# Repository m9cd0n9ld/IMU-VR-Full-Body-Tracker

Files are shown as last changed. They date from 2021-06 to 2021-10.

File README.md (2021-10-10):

# IMU-VR-Full-Body-Tracker
 Inside-out full body tracker for Steam VR based on ESP32 with BNO080/085 IMU.  
 Support up to 2 BNO08X IMUs per ESP32 via I2C communication.  
 No base station is required, completely wireless using WiFi UDP.  
 Should be compatible with any VR headset that supports Steam VR.  
 <p align="middle">
 
 
 </p>
 
## Hardware Example
 **LILYGO® TTGO T7 V1.5 Mini32 ESP32-WROVER-B** with **GY-BNO08X**  
 <p align="middle">
 
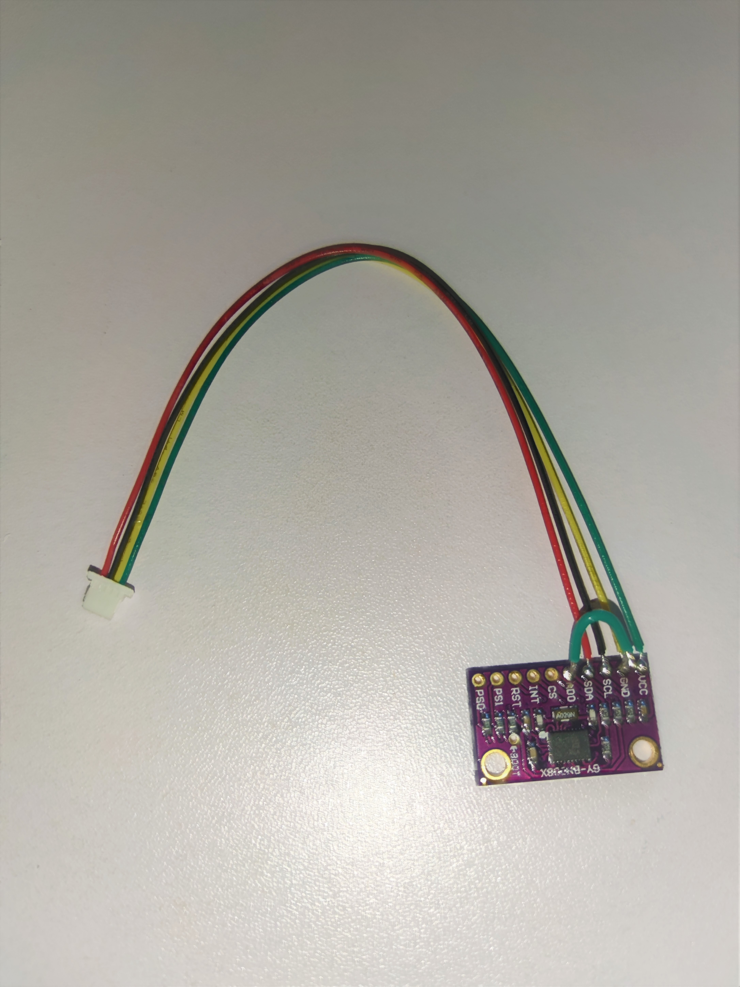
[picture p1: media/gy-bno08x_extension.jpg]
 
 <p/>
 <p align="middle">
 
 
 
 <p/>
 <p/>
 <p align="middle">
 
 <p/>

## Instruction
 1. Extract steamvr.driver.zip and copy imuFBT folder to (Steam directory)\steamapps\common\SteamVR\drivers.  
 2. Extract esp32.sketch.zip, edit the settings (pin settings, etc.) in esp32_settings.h file.  
 3. Upload the sketch to ESP32 microcontroller with Arduino IDE (SparkFun_BNO080_Arduino_Library Arduino library is required).  
 4. Extract desktop.server.zip. Add imufbtserver.exe and backend/imuFBTServerBackend.exe to Windows firewall exception list to allow UDP to work properly.  
 5. Run the imufbtserver.exe (might trigger antivirus false positive, known problem for unsigned PyInstaller exe files).  
 6. Set the tracker sensor frame to driver frame (X right, Y up, Z back) XYZ intrinsic rotation based on the mounting orientation, body segment length, tracker virtual position and offset settings when standing in T-pose** in **Main settings** and **Tracker virtual position settings** tab.  
 7. Activate required tracker devices to be output to SteamVR. In some SteamVR game/program, the hand controllers might lose tracking or not working if too many tracker devices are activated.  
 8. Set the tracker floor level offset (tracker min Y value to prevent clipping) if necessary.  
 9. Enable lower leg tracker data as SteamVR feet tracker if want to use lower leg tracker as foot role. Feet tracker device must still be activated.  
 10. Save the settings by pressing **Save settings** button or load an existing saved settings by pressing **Load settings** button in **Main settings** tab. The last saved/loaded settings will be automatically loaded in the next instance.  
 <p align="middle">
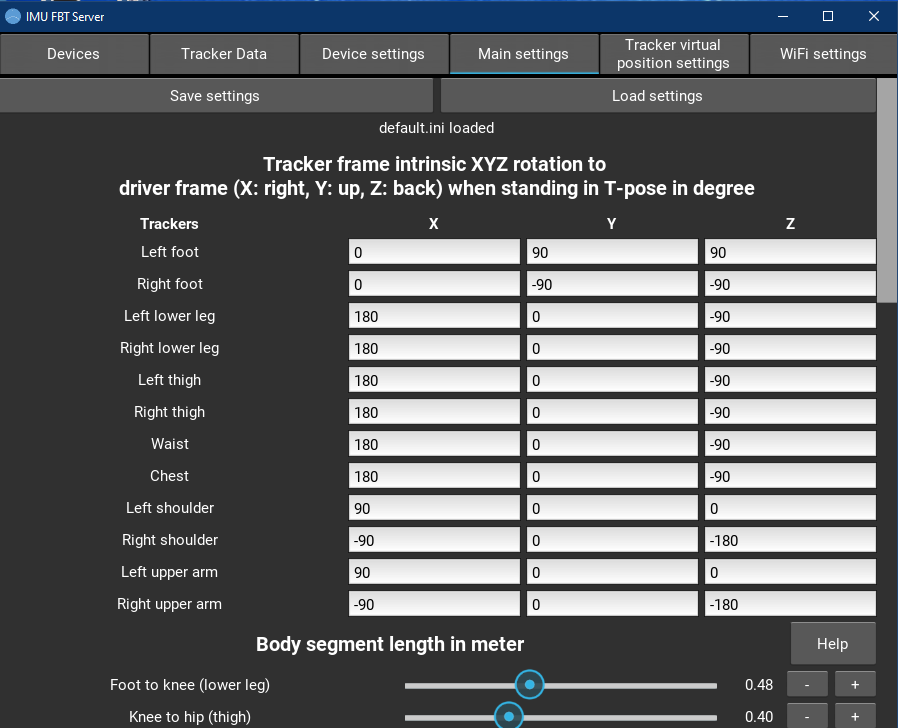
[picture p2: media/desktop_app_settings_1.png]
 
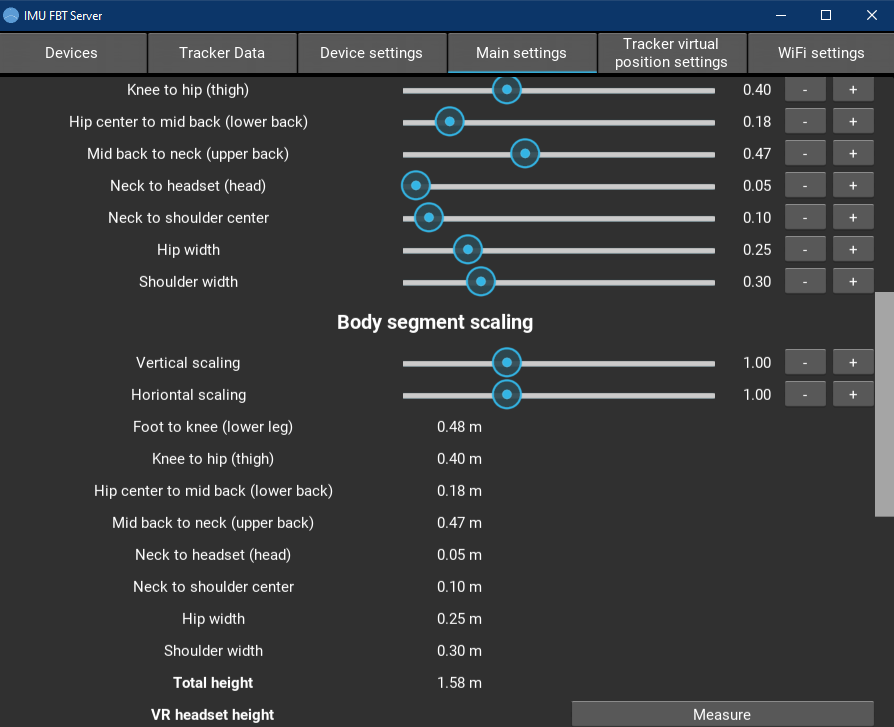
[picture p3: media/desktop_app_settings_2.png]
 
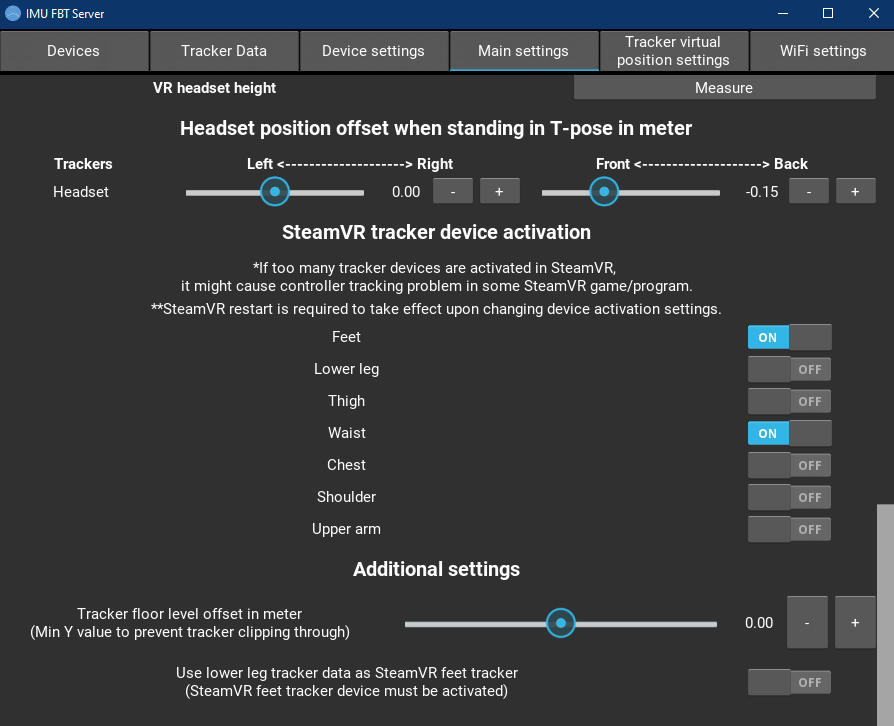
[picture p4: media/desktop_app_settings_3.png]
 
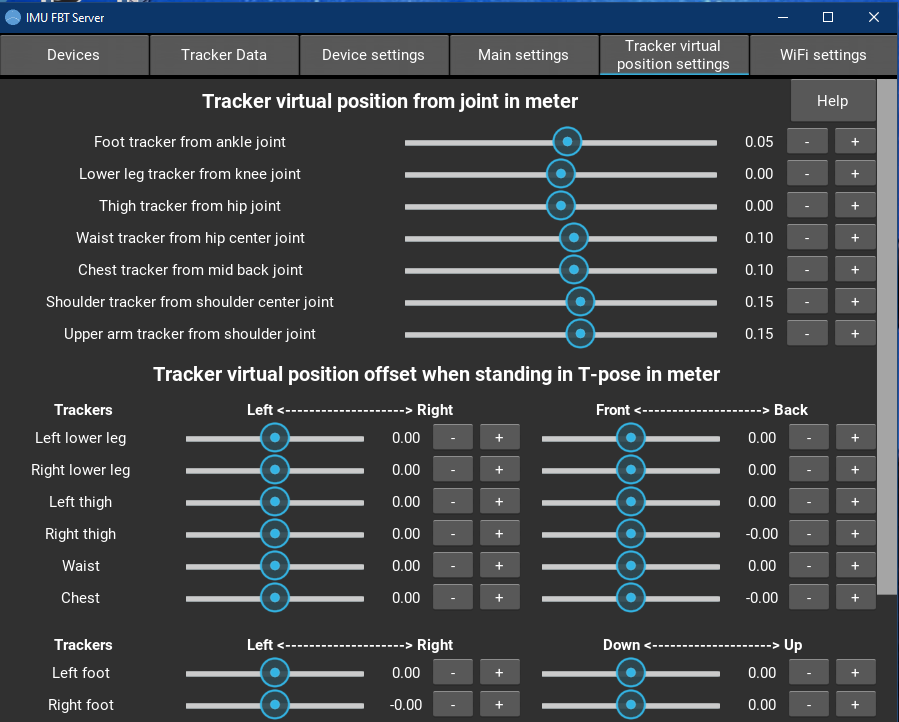
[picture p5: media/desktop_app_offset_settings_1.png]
 
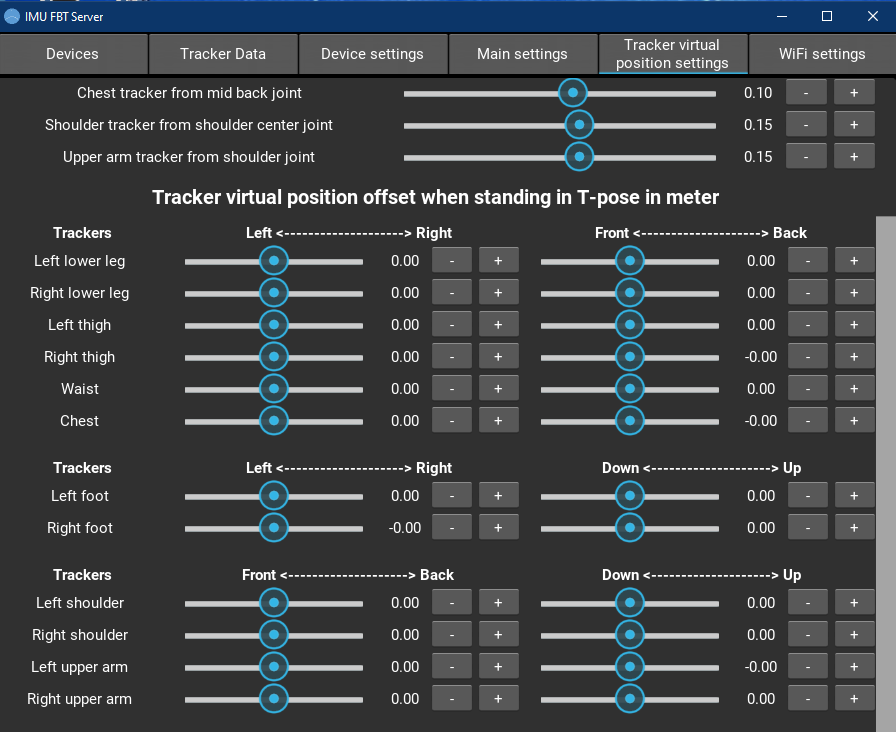
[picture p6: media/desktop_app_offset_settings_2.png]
 
 <p/>
 
 11. Plug in USB cable to ESP32 and set the WiFi credential in **WiFi Settings** tab.  
 <p align="middle">
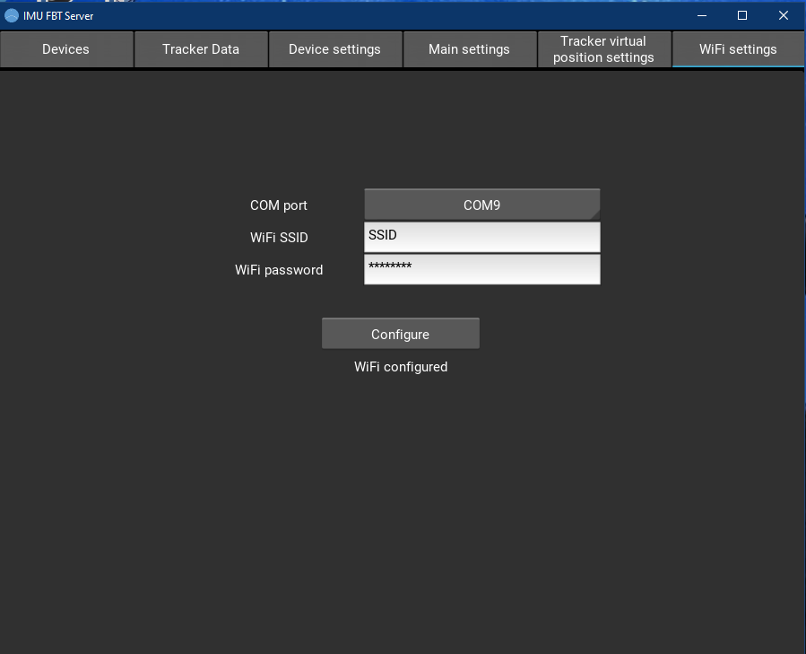
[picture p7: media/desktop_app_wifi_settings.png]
 
 <p/>
 
 12. Once WiFi credential is configured, unplug the USB cable and power cycle the ESP32 to establish WiFi connection.  
 13. The trackers will be listed in **Device settings** tabs.  
 14. Set the IMU mode, WiFi TX power, WiFi power saving mode and role of the trackers in **Device settings** tab.  
 <p align="middle">
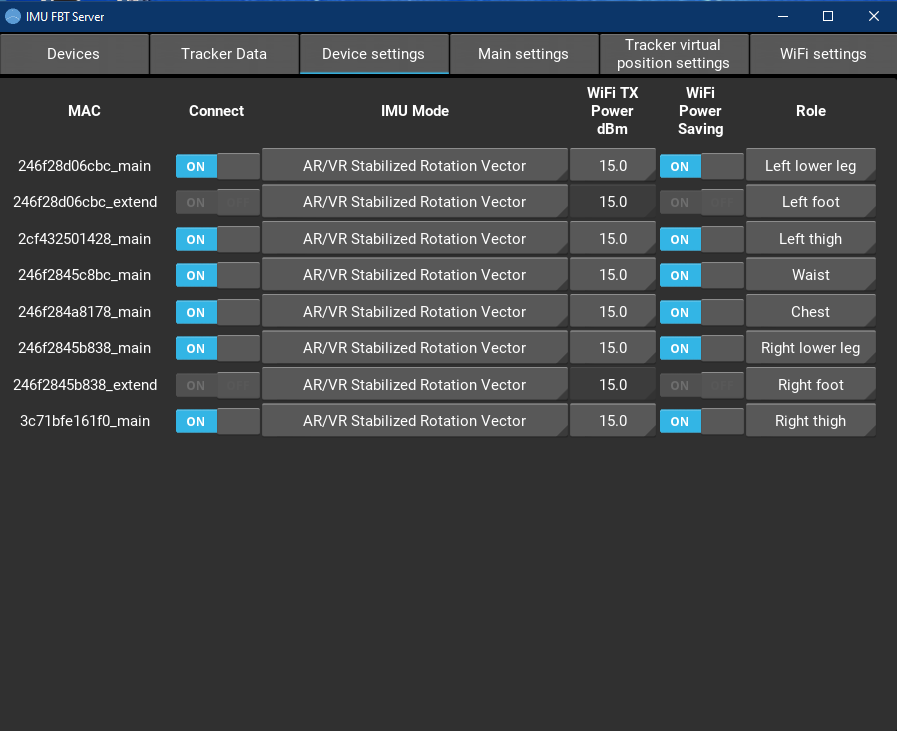
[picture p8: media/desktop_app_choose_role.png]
 
 <p/>
 
 15. Click **Connect** slider, and the trackers with correct settings will be shown in **Devices** tab.  
 16. Save the settings in **Main settings** tab to save the device settings.  
 <p align="middle">
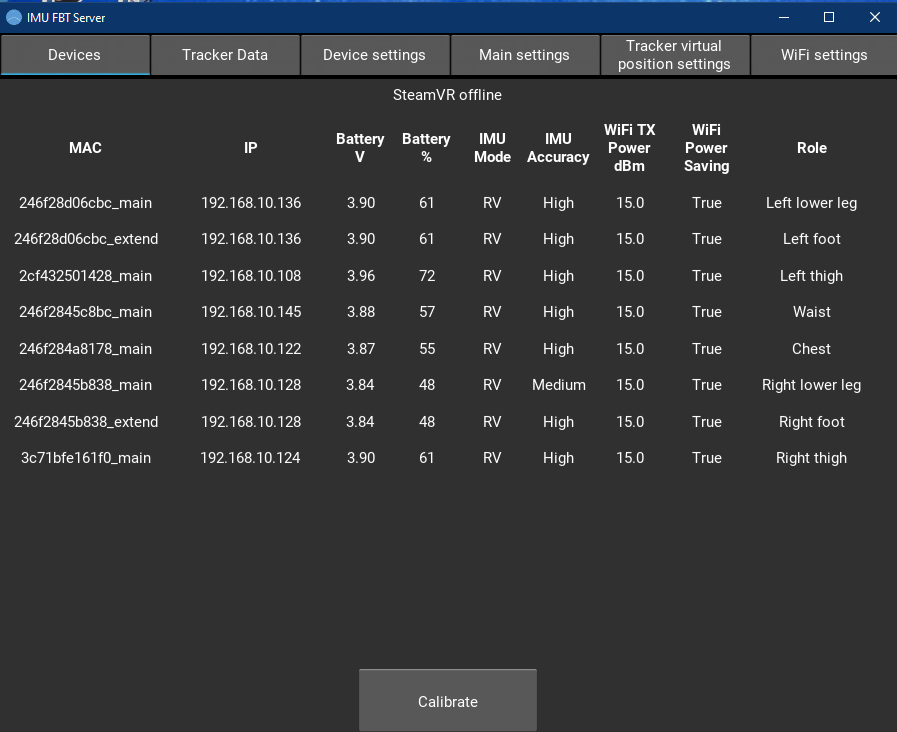
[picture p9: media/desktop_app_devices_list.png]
 
 <p/>
 
 17. Mount the trackers according to the following diagram. For feet/leg tracking, chest tracker, waist tracker, thigh trackers and lower leg trackers are required. Feet trackers are optional. For elbow tracking, chest tracker, shoulder trackers and upper arm trackers are required.  
 <p align="middle">
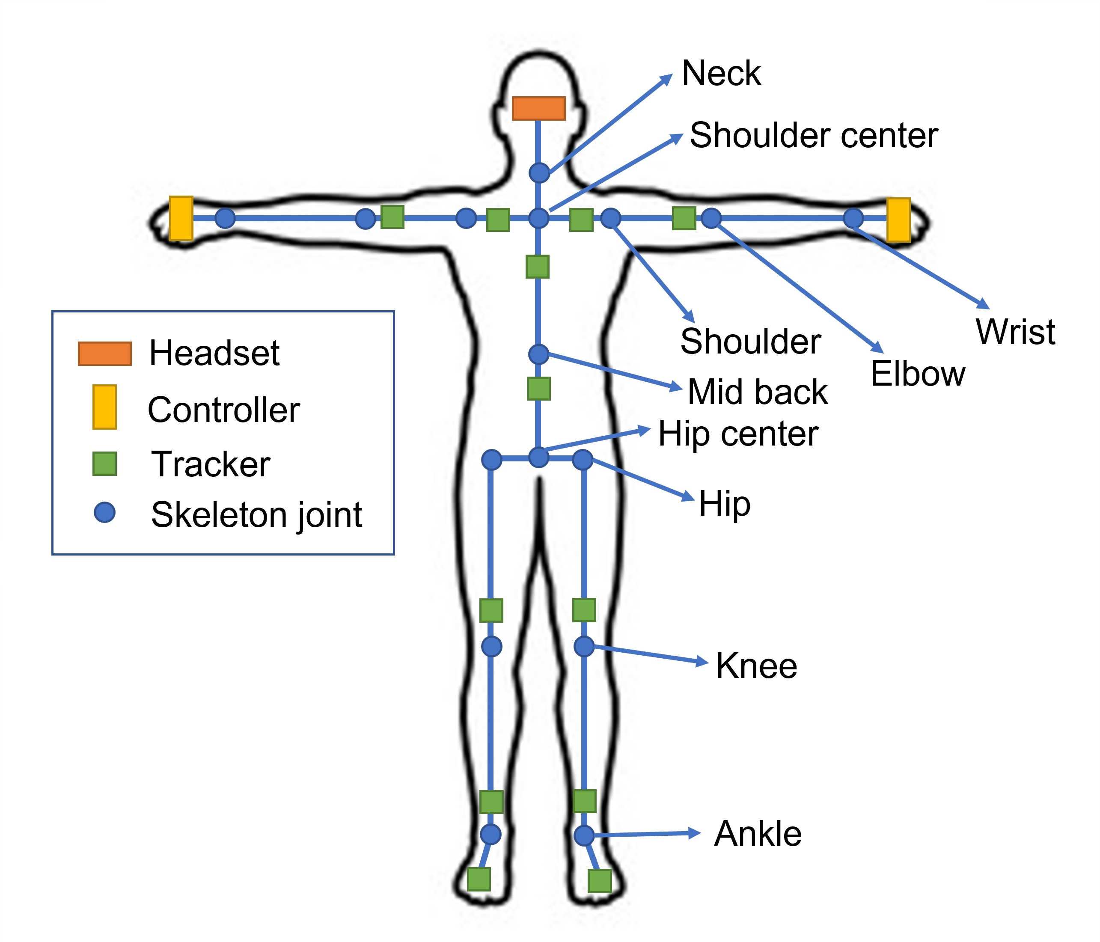
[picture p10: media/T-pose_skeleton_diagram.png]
 
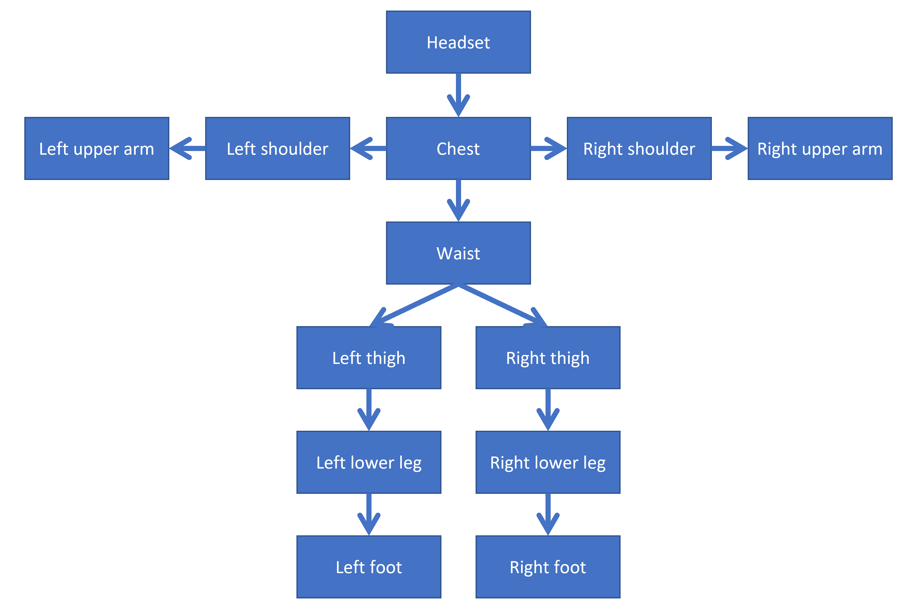
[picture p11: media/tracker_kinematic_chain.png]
 
 <p/>
 
 18. Open SteamVR. The top of the **Devices** tab will show SteamVR online when SteamVR is detected.  
 19. The trackers will be shown in SteamVR environment at weird position and orientation on startup.  
 20. Stand in T-pose**, then press **Calibrate** button in **Devices** tab to realign/calibrate the trackers.  
 <p align="middle">
 
 <p/>
 
 21. Tracker output data can be seen on **Tracker Data** tab.  
 <p align="middle">
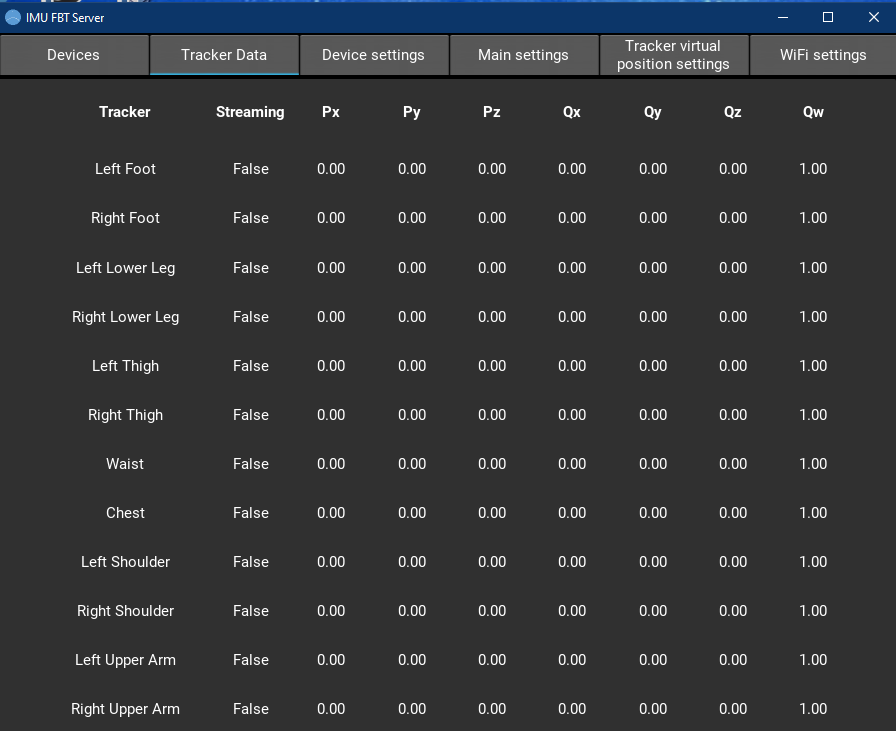
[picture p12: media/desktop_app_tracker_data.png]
 
 <p/>
 
 22. Done!  
 <p align="middle">
 
 
 <p/>
 
 **Stand straight look forward with feet pointing forward and hip-width apart in T-pose with palm facing down.

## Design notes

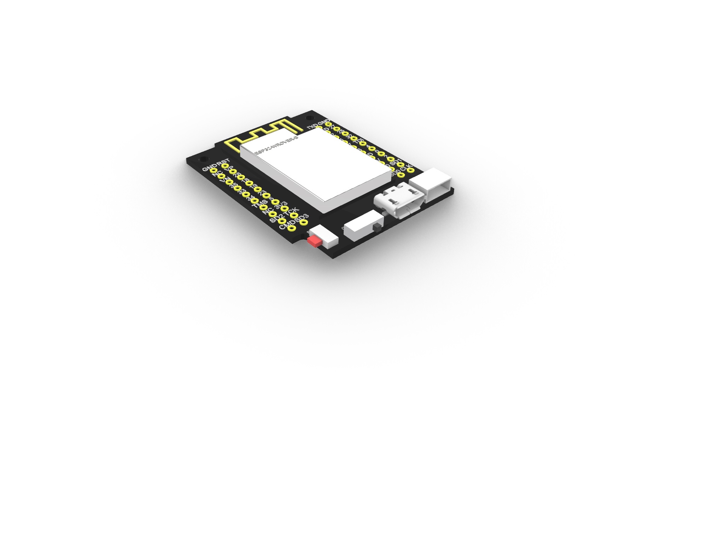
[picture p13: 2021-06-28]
hardware example/TTGO-T7-V1.5_GY-BNO08X_enclosure/esp32-lilygo-t7-mini-v1-4-1.snapshot.2/ttgo_mini_b.jpg

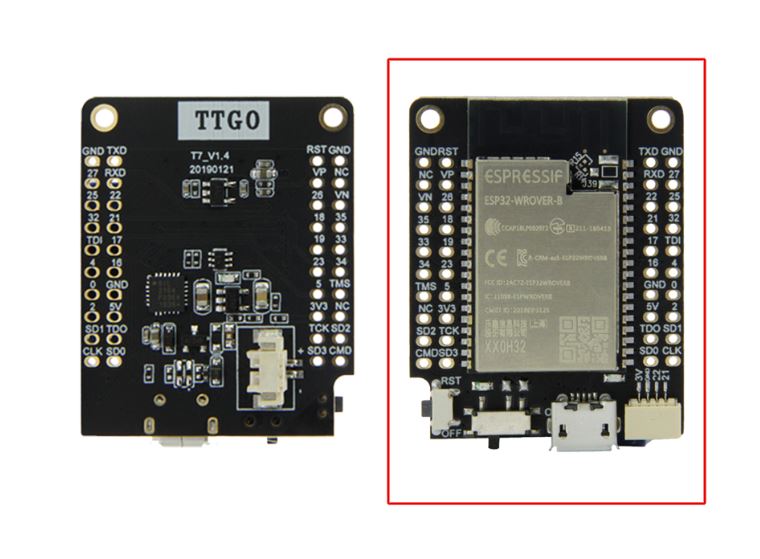
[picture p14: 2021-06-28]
hardware example/TTGO-T7-V1.5_GY-BNO08X_enclosure/esp32-lilygo-t7-mini-v1-4-1.snapshot.2/ESP32 LILYGO T7 TTGO MINI.JPG

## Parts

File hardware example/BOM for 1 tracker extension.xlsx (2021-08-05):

Items | Quantity
GY-BNO08X | 1
JST-SH 1mm pitch 4 pin cable | 1
10mm M2 female-female standoff | 2
12mm M2 female-female standoff | 2
5mm M2 screw | 6
8mm M2 screw | 2
GY-BNO08X extension enclosure | 1
30 mm width strap | 1

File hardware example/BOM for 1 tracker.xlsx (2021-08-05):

Items | Quantity
TTGO T7 v1.5 | 1
GY-BNO08X | 1
TTGO T7 v1.5 - GY-BNO08X breakout board | 1
803040 LiPo | 1
0.1" 1x10 female header with 5mm height | 2
0.1" 1x10 male header for 5mm female header | 2
13mm M2 female-female standoff | 2
27mm M3 female-female standoff | 4
5mm M2 screw | 4
5mm M3 screw | 8
TTGO T7 v1.5 - GY-BNO08X enclosure | 1
38 mm width strap | 1

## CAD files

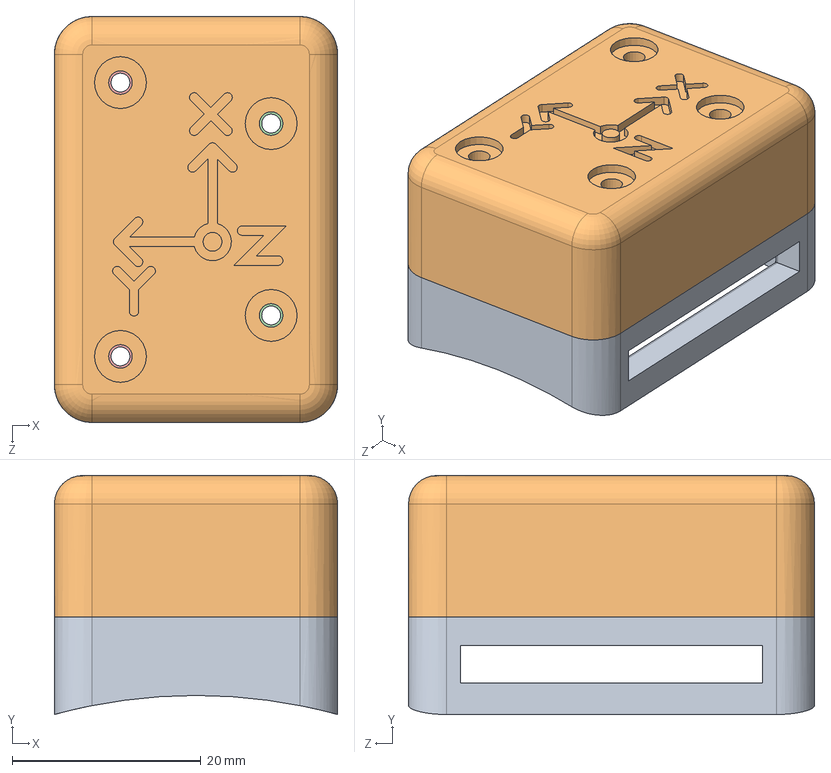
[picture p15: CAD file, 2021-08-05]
hardware example/GY-BNO08X_extension_enclosure/assembly.SLDASM
30.0 x 25.3 x 43.0 mm
base
cover
GY-BNO08X
m2x10-standoff x 2
m2x12-standoff x 2

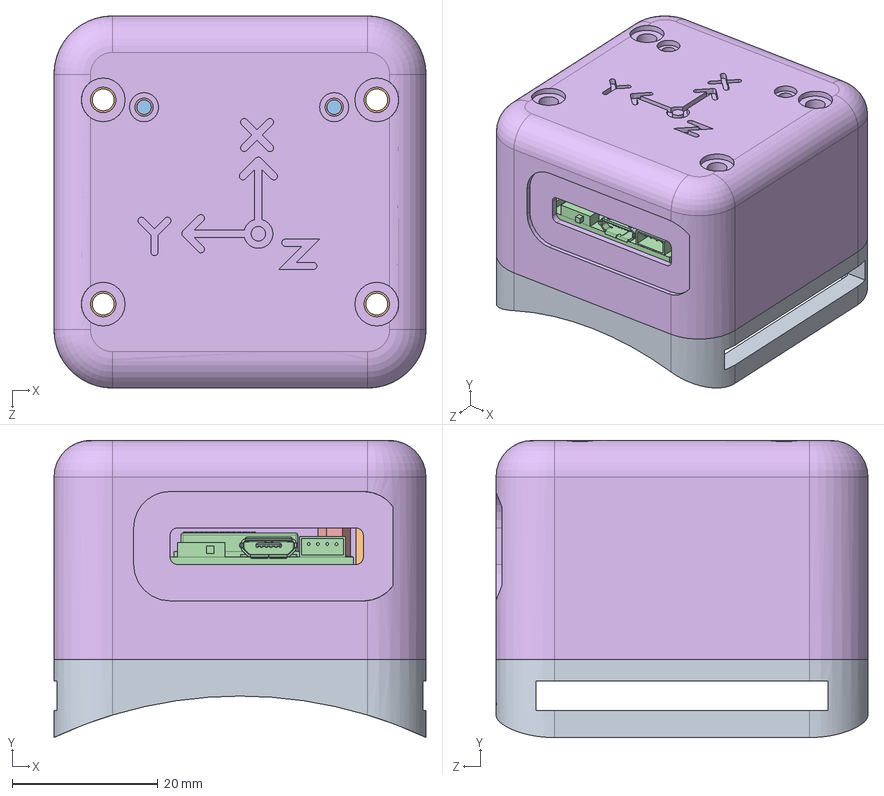
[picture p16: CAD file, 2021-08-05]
hardware example/TTGO-T7-V1.5_GY-BNO08X_enclosure/assembly.SLDASM
51.0 x 40.7 x 51.0 mm
base
m3-standoff x 4
LiPo-803040
ttgo_t7_v1.5_board
m2-standoff x 2
cover

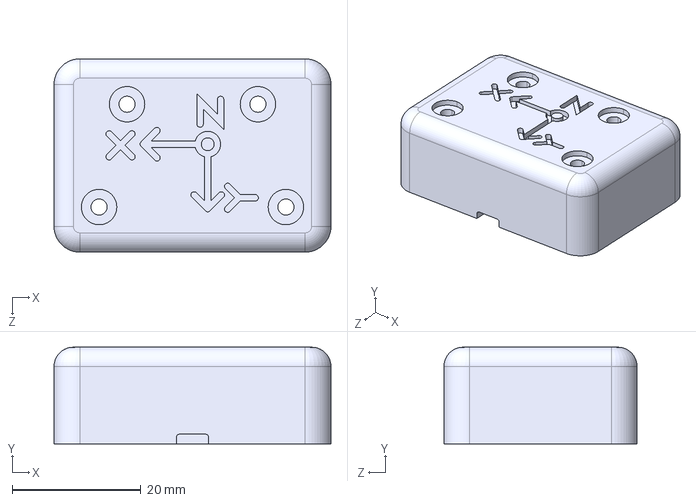
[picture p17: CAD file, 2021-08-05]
hardware example/GY-BNO08X_extension_enclosure/stp/cover.STEP
43.0 x 15.0 x 30.0 mm

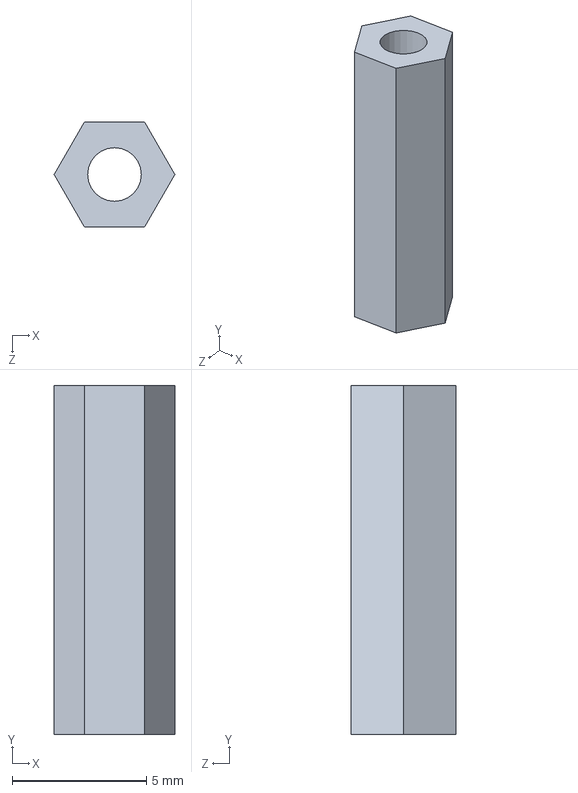
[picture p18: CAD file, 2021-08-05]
hardware example/TTGO-T7-V1.5_GY-BNO08X_enclosure/m2-standoff.SLDPRT
4.50 x 13.0 x 3.90 mm

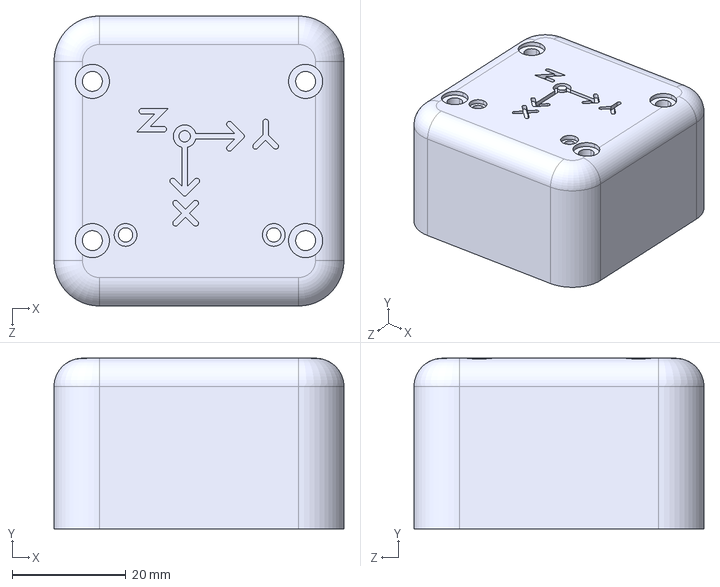
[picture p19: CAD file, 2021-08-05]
hardware example/TTGO-T7-V1.5_GY-BNO08X_enclosure/stp/cover.STEP
51.0 x 30.0 x 51.0 mm

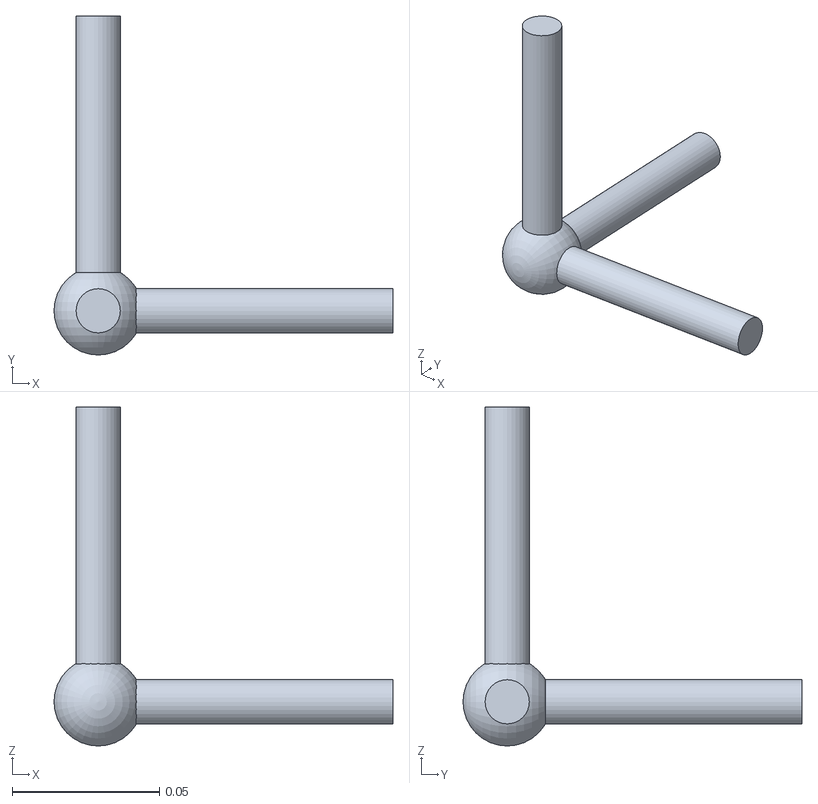
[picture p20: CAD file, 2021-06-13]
steamvr_openvr_driver/driver_imuFBT/resources/resources/rendermodels/frame/frame.obj
0.115 x 0.115 x 0.115

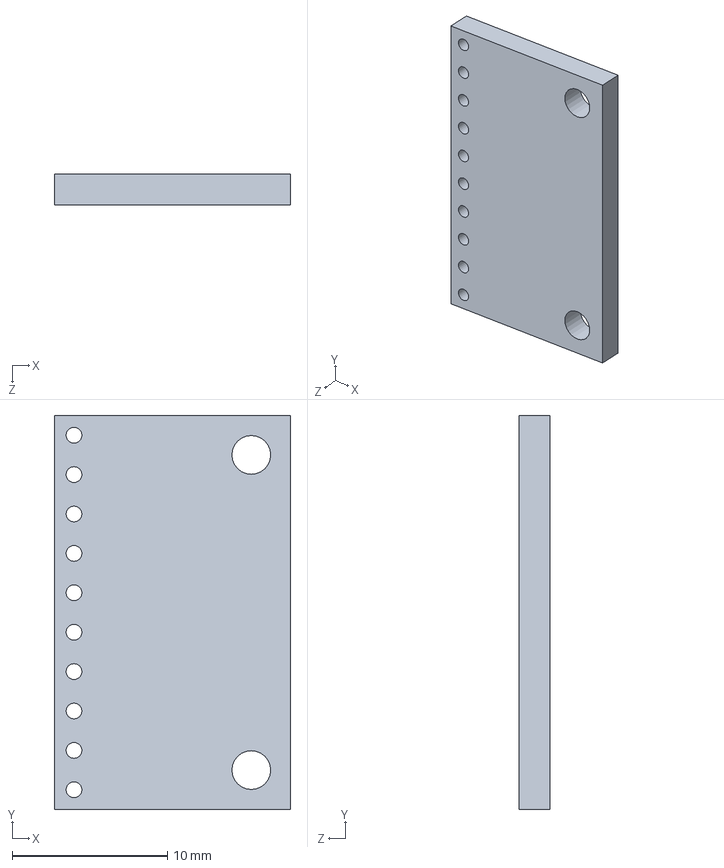
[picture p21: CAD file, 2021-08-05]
hardware example/GY-BNO08X_extension_enclosure/GY-BNO08X.SLDPRT
15.2 x 25.4 x 2.00 mm

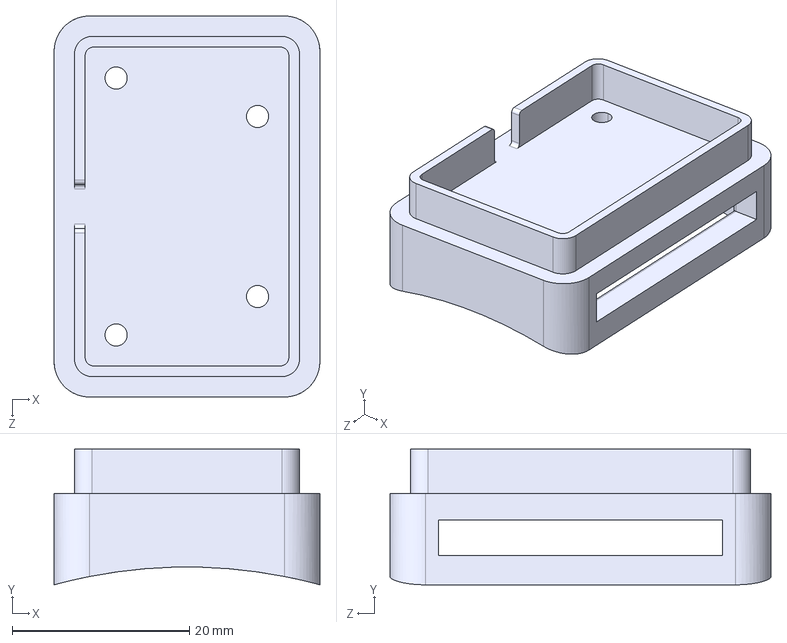
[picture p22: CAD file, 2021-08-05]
hardware example/GY-BNO08X_extension_enclosure/stp/base.STEP
30.0 x 15.3 x 43.0 mm

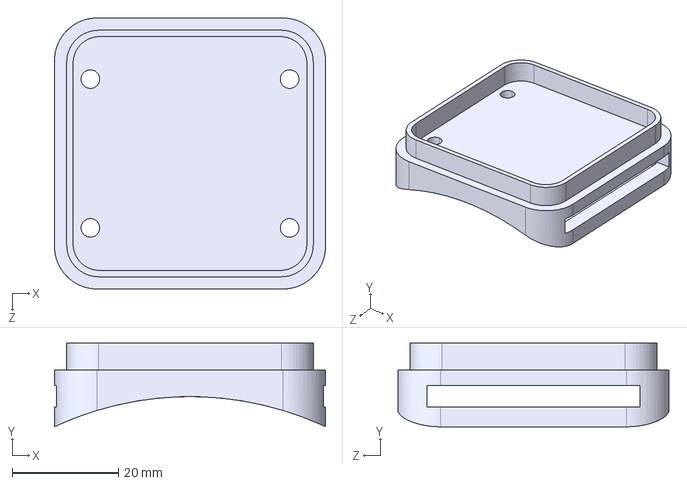
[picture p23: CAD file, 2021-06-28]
hardware example/TTGO-T7-V1.5_GY-BNO08X_enclosure/stp/base.STEP
51.0 x 15.7 x 51.0 mm

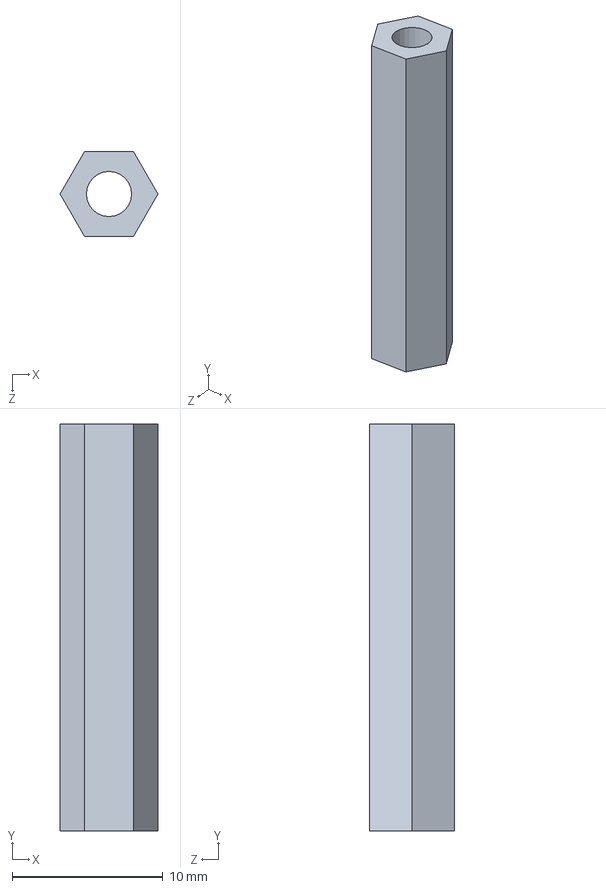
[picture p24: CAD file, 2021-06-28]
hardware example/TTGO-T7-V1.5_GY-BNO08X_enclosure/m3-standoff.SLDPRT
6.50 x 27.0 x 5.63 mm

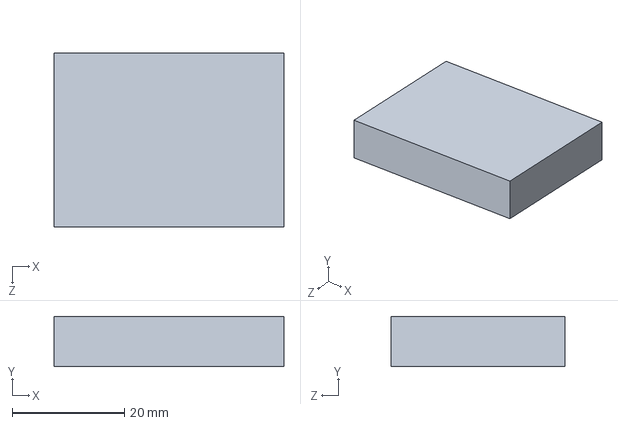
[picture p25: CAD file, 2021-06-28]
hardware example/TTGO-T7-V1.5_GY-BNO08X_enclosure/LiPo-803040.SLDPRT
41.0 x 9.00 x 31.0 mm

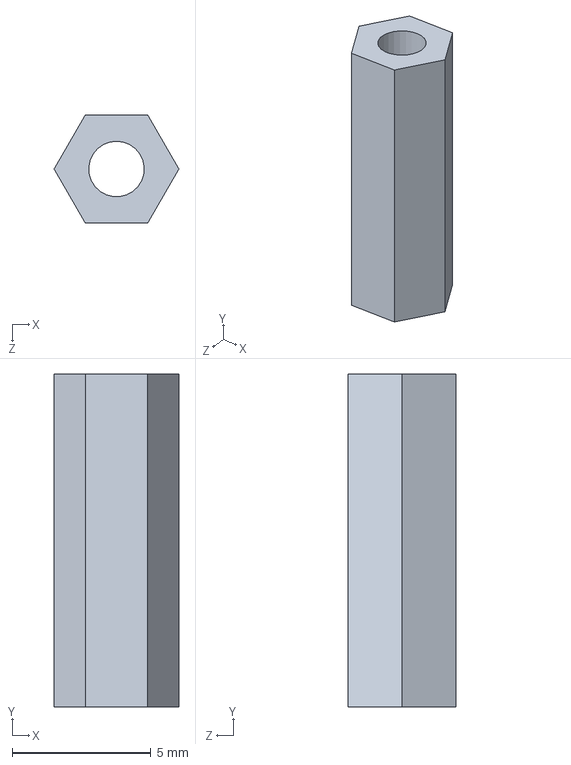
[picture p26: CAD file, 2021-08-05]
hardware example/GY-BNO08X_extension_enclosure/m2x12-standoff.SLDPRT
4.50 x 12.0 x 3.90 mm

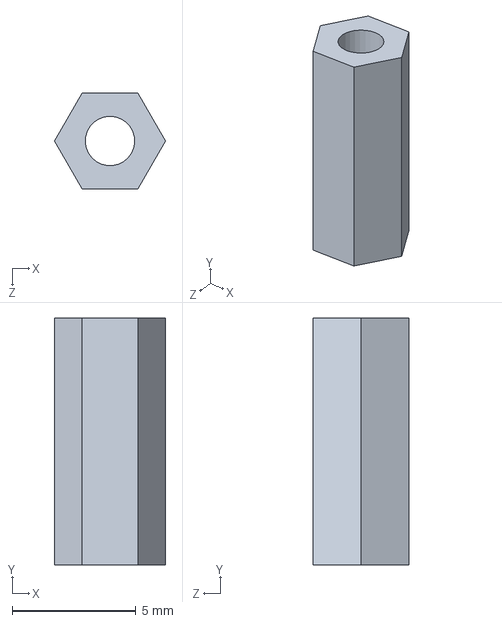
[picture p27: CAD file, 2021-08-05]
hardware example/GY-BNO08X_extension_enclosure/m2x10-standoff.SLDPRT
4.50 x 10.0 x 3.90 mm

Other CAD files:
hardware example/GY-BNO08X_extension_enclosure/base.SLDPRT
hardware example/GY-BNO08X_extension_enclosure/cover.SLDPRT
hardware example/TTGO-T7-V1.5_GY-BNO08X_enclosure/base.SLDPRT
hardware example/TTGO-T7-V1.5_GY-BNO08X_enclosure/cover.SLDPRT

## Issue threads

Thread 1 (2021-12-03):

BNO055

kennibaz, 2021-12-03:
Is it possible to substitute BNO085 with BNO055?

m9cd0n9ld, 2021-12-04:
As long as the IMU sensor or AHRS algorithm can provide quaternion in ENU coordinate, any IMU sensor can be used, just need to do some minor modification in the Arduino sketch code. But for best result, it's better to use high quality AHRS output IMU such as BNO085, etc.

kennibaz, 2021-12-04:
Thanks for your reply. The reason I’m asking about the substitute is bc
there is a huge shortage of bno085.
Could be mpu 6050 used as well?

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

m9cd0n9ld, 2021-12-04:
I see mpu6050 can output quaternion, shouldn't be a problem.

kennibaz, 2021-12-04:
Great, thanks!

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

Closed 2021-12-04.

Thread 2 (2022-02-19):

Pose estimates from 6 IMUs

NoLoPhe, 2022-02-19:
Hi!

I made pose estimates from 6 IMUs based on the results of the paper TransPose.
I want it to work with VRchat. How do I do that?

I don't see documentation to send skeleton coordinates to Openvr.

Thankyou!

Link: https://twitter.com/Tn23008624/status/1494618444821839877

m9cd0n9ld, 2022-02-19:
Dear @NoLoPhe , you need to create Steam VR driver that reads the skeleton coordinates data, then output them as steam tracker devices to Steam VR. You can refer to steamvr_openvr_driver directory for example.

NoLoPhe, 2022-02-19:
@m9cd0n9ld Thanks for the quick response, I'll take a look at the code.

Closed 2022-02-22.

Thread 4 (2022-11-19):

Need help in understanding the code's logic

TparT, 2022-11-19:
Hi there! Im looking into making a full body tracking suit for a school project and I found your repo which looks really nice.
Only problem is I cant figure out much about the order of the logic, like how and when do I set the tracker location, when is the data transmitted to SteamVR etc..

We could also move to a different chatting platform like Discord if that would make things easier.

So, if you could help me out and guide me through the code it would be very very appreciated :D

m9cd0n9ld, 2022-11-21:
Hi @TparT,

If you are interested in algorithm behind it, you can just implement this [header](https://github.com/m9cd0n9ld/IMU-VR-Full-Body-Tracker/blob/main/imuFBTServerBackend/headers/kinematics.h) file to your project. It might not be the best solution for full body tracking.

TparT, 2022-11-23:
Okay, I guess I missed the part where you need to enable the trackers in the 'Main settings' tab really down there. Thanks anyways for replying and trying to help :D

Closed 2022-11-23.

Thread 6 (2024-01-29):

Looking for some help

erik-aranda, 2024-01-29:
Hi, I try to make a **MPU6050 remplacement** to the device that using right now but I don't have it cuz in my country it costs 80 usd each one, and MPU6050 it costs 7 usd. So **if you have some code that help me will be nice.** Also I am testing with python but I don't see that the bones move correctly. I mean that it will only hand moves but the others bones never. So I was looking for the error and for now I check driver IMU folder and **some files are without information some are with "None" parameters** and this is wrong. **I need make sure that right now your original code it works, please confirm me too if is working in this date with your original sensor.**

[erik-aranda:patch-1](url)

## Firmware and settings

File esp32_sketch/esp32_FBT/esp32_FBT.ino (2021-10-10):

#include <esp_wifi.h>
#include <WiFi.h>
#include <WiFiUdp.h>
#include <AsyncUDP.h>
#include "esp32_settings.h"
#include <Wire.h>
#include "SparkFun_BNO080_Arduino_Library.h"

#define DEBUG false
#define DEBUG_PRINT if(DEBUG)Serial

#define ROTVEC 0
#define GAMEROTVEC 1

char header[128];
char networkSSID[128];
char networkPassword[128];
uint16_t serialLength;

IPAddress udpAddress(0, 0, 0, 0);
const uint16_t broadPort = 6969;
uint16_t serverPort = 0;
uint16_t driverPort = 0;

bool connected = false;

WiFiUDP udp;
AsyncUDP Audp;

struct __attribute__((packed)) PingBroad {
  uint8_t header = (uint8_t)'I';
  uint8_t id = 77;
  uint8_t a;
  uint8_t b;
  uint8_t c;
  uint8_t d;
  uint8_t e;
  uint8_t f;
  bool extend = false;
  uint8_t footer = (uint8_t)'i';
} pingbroad;

struct __attribute__((packed)) Ping {
  uint8_t header = (uint8_t)'I';
  uint8_t id = 0;
  uint8_t id_ext = 0;
  uint8_t a;
  uint8_t b;
  uint8_t c;
  uint8_t d;
  uint8_t e;
  uint8_t f;
  float batt = 0;
  uint8_t mode;
  uint8_t mode_ext;
  uint8_t accuracy = 0;
  uint8_t accuracy_ext = 0;
  uint8_t wifi_power;
  uint8_t wifi_sleep;
  bool extend = false;
  uint8_t footer = (uint8_t)'i';
} ping;

struct __attribute__((packed)) Ack {
  uint8_t header;
  uint8_t reply;
  uint8_t id;
  uint8_t id_ext;
  uint8_t mode;
  uint8_t mode_ext;
  uint8_t wifi_power;
  uint8_t wifi_sleep;
  uint16_t serverPort;
  uint16_t driverPort;
  uint8_t footer;
} ack;

struct __attribute__((packed)) PayloadExt {
  uint8_t header = (uint8_t)'I';
  uint8_t id = 0;
  int16_t x = 0;
  int16_t y = 0;
  int16_t z = 0;
  int16_t w = 32767;
  uint8_t id_ext = 0;
  int16_t x_ext = 0;
  int16_t y_ext = 0;
  int16_t z_ext = 0;
  int16_t w_ext = 32767;
  uint8_t footer = (uint8_t)'i';
} payloadext;

struct __attribute__((packed)) Payload {
  uint8_t header = (uint8_t)'I';
  uint8_t id = 0;
  int16_t x = 0;
  int16_t y = 0;
  int16_t z = 0;
  int16_t w = 32767;
  uint8_t footer = (uint8_t)'i';
} payload;

uint32_t last_broadcast;
uint32_t last_ping;
uint32_t last_main_imu_check;
uint32_t last_extend_imu_check;
uint32_t last_udp_check;
uint32_t recv_watchdog;
uint32_t t_blink;
uint8_t led_state = 0;
BNO080 myIMU;
BNO080 myIMU2;
bool extended_imu_found = false;

uint8_t main_id = 0;
uint8_t extended_id = 0;

uint8_t imu_mode = 101;
uint8_t imu_mode_ext = 101;

uint8_t wifi_power = 78;
uint8_t wifi_sleep = 1;

bool streaming_udp = false;
bool imu_start = false;

bool first_read = false;
bool first_read_ext = false;

float battery_voltage() {
  return get_battery_voltage(analogReadMilliVolts(batt_monitor_pin));
}

void reset_imu() {
  digitalWrite(reset_pin, HIGH);
  delay(100);
  digitalWrite(reset_pin, LOW);
  delay(100);
  digitalWrite(reset_pin, HIGH);
}

void blink_led(uint16_t interval) {
  if (!led_state) {
    if (millis() - t_blink >= interval) {
      led_state = !led_state;
      digitalWrite(led_pin, led_state);
      t_blink = millis();
    }
  }
  else {
    if (millis() - t_blink >= 100) {
      led_state = !led_state;
      digitalWrite(led_pin, led_state);
      t_blink = millis();
    }
  }
}

int16_t map(float x, float in_min = -1, float in_max = 1, float out_min = -32767, float out_max = 32767) {
  return (int16_t)((x - in_min) * (out_max - out_min) / (in_max - in_min) + out_min);
}

void sendUDP(bool extend) {
  if ((driverPort != 0) && ((main_id != 0) || (extended_id != 0))) {
    udp.beginPacket(udpAddress, driverPort);
    if (extend) {
      udp.write((uint8_t*)&payloadext, sizeof(payloadext));
    }
    else {
      udp.write((uint8_t*)&payload, sizeof(payload));
    }
    
    if (udp.endPacket()) {
      last_udp_check = millis();
    }

    DEBUG_PRINT.print("main,");
    DEBUG_PRINT.print(payload.id);
    DEBUG_PRINT.print(",");
    DEBUG_PRINT.print(payload.x);
    DEBUG_PRINT.print(",");
    DEBUG_PRINT.print(payload.y);
    DEBUG_PRINT.print(",");
    DEBUG_PRINT.print(payload.z);
    DEBUG_PRINT.print(",");
    DEBUG_PRINT.print(payload.w);
    DEBUG_PRINT.println();

    DEBUG_PRINT.print("extended,");
    DEBUG_PRINT.print(payloadext.id_ext);
    DEBUG_PRINT.print(",");
    DEBUG_PRINT.print(payloadext.x_ext);
    DEBUG_PRINT.print(",");
    DEBUG_PRINT.print(payloadext.y_ext);
    DEBUG_PRINT.print(",");
    DEBUG_PRINT.print(payloadext.z_ext);
    DEBUG_PRINT.print(",");
    DEBUG_PRINT.print(payloadext.w_ext);
    DEBUG_PRINT.println();
  }
}

void setIMUMode(uint8_t mode, uint8_t mode_ext) {
  if (imu_mode != mode) {
    imu_mode = mode;
    switch (imu_mode) {
      case ROTVEC:
      myIMU.enableARVRStabilizedRotationVector(10);
      myIMU.enableARVRStabilizedGameRotationVector(0);
      DEBUG_PRINT.println("AR VR Stabilized Rotation Vector enabled on main IMU");
      break;

      case GAMEROTVEC:
      myIMU.enableARVRStabilizedRotationVector(0);
      myIMU.enableARVRStabilizedGameRotationVector(10);
      DEBUG_PRINT.println("AR VR Stabilized Game Rotation Vector enabled on main IMU");
      break;
    }
    first_read = false;
  }

  if (extended_imu_found && (imu_mode_ext != mode_ext)) {
    imu_mode_ext = mode_ext;
    switch (imu_mode_ext) {
      case ROTVEC:
      myIMU2.enableARVRStabilizedRotationVector(10);
      myIMU2.enableARVRStabilizedGameRotationVector(0);
      DEBUG_PRINT.println("AR VR Stabilized Rotation Vector enabled on extended IMU");
      break;

      case GAMEROTVEC:
      myIMU2.enableARVRStabilizedRotationVector(0);
      myIMU2.enableARVRStabilizedGameRotationVector(10);
      DEBUG_PRINT.println("AR VR Stabilized Game Rotation Vector enabled on extended IMU");
      break;
    }
    first_read_ext = false;
  }
}

void setWiFiPower(uint8_t power) {
  if (wifi_power != power) {
    wifi_power = power;
    esp_wifi_set_max_tx_power(wifi_power);
    DEBUG_PRINT.print("WiFi TX Power: ");
    DEBUG_PRINT.println(wifi_power);
    int8_t power_check;
    esp_wifi_get_max_tx_power(&power_check);
    DEBUG_PRINT.print("WiFi TX Power check: ");
    DEBUG_PRINT.println(power_check);
  }
}

void setWiFiSleep(uint8_t sleep) {
  if (wifi_sleep != sleep) {
    wifi_sleep = sleep;
    WiFi.setSleep(wifi_sleep);
    DEBUG_PRINT.print("WiFi Sleep Mode: ");
    DEBUG_PRINT.println(wifi_sleep);
    DEBUG_PRINT.print("WiFi Sleep Mode check: ");
    DEBUG_PRINT.println(WiFi.getSleep());
  }
}

void setup(){
  if (!brown_en) {
    WRITE_PERI_REG(RTC_CNTL_BROWN_OUT_REG, 0);
  }
  
  setCpuFrequencyMhz(80);

  uint8_t mac[6];
  WiFi.macAddress(mac);
  ping.a = mac[0];
  ping.b = mac[1];
  ping.c = mac[2];
  ping.d = mac[3];
  ping.e = mac[4];
  ping.f = mac[5];

  pingbroad.a = mac[0];
  pingbroad.b = mac[1];
  pingbroad.c = mac[2];
  pingbroad.d = mac[3];
  pingbroad.e = mac[4];
  pingbroad.f = mac[5];
  
  Serial.begin(115200);
  
  WiFi.onEvent(WiFiEvent);
  WiFi.begin();
  esp_wifi_set_max_tx_power(wifi_power);
  WiFi.setSleep(wifi_sleep);

  pinMode(reset_pin, OUTPUT);
  digitalWrite(reset_pin, HIGH);
  reset_imu();
  Wire.begin();
  uint32_t imu_init_time = millis();
  while (!myIMU.begin(i2c_main_addr)) {
    reset_imu();
    delay(500);
    if (millis() - imu_init_time >= 3000) {
      ESP.deepSleep(1000);
    }
  }
  Wire.setClock(400000);

  if (myIMU2.begin(i2c_extend_addr)) {
    extended_imu_found = true;
    ping.extend = true;
    pingbroad.extend = true;
    DEBUG_PRINT.println("Extended IMU found");
  }
  else {
    extended_imu_found = false;
    ping.extend = false;
    pingbroad.extend = false;
    DEBUG_PRINT.println("Extended IMU not found");
  }

  pinMode(led_pin, OUTPUT);
  
  t_blink = millis();

  if (!brown_en) {
    WRITE_PERI_REG(RTC_CNTL_BROWN_OUT_REG, 1);
  }
}

void loop(){
  serialLength = Serial.available();
  if (serialLength) {
    Serial.readBytesUntil('\n', header, sizeof(header));
    if (String(header) == "111") {
      Serial.readBytesUntil('\n', networkSSID, sizeof(networkSSID));
      Serial.readBytesUntil('\n', networkPassword, sizeof(networkPassword));
      connectToWiFi(networkSSID, networkPassword);
      Serial.write(110);
    }
    else {
      char junk[serialLength];
      Serial.readBytes(junk, sizeof(junk));
    }
    memset(header, 0, sizeof(header));
    memset(networkSSID, 0, sizeof(networkSSID));
    memset(networkPassword, 0, sizeof(networkPassword));
  }
  
  if(connected){
    
    udp.parsePacket();
    if (udp.read((uint8_t*)&ack, sizeof(ack)) == sizeof(Ack)) {
      if (ack.reply == 200 && ack.header == (uint8_t)'I' && ack.footer == (uint8_t)'i') {
        recv_watchdog = millis();
        udpAddress = udp.remoteIP();
        main_id = ack.id;
        extended_id = ack.id_ext;
        setIMUMode(ack.mode, ack.mode_ext);
        setWiFiPower(ack.wifi_power);
        setWiFiSleep(ack.wifi_sleep);
        serverPort = ack.serverPort;
        driverPort = ack.driverPort;
        if ((driverPort != 0) && ((main_id != 0) || (extended_id != 0))) {
          if (!streaming_udp) {
            streaming_udp = true;
            last_udp_check = millis();
          }
        }
        else {
          streaming_udp = false;
        }
      }
    }
    
    if (udpAddress != IPAddress(0, 0, 0, 0)) {

      if (!imu_start) {
        imu_start = true;
        last_main_imu_check = millis();
        last_extend_imu_check = millis();
      }

      if (!first_read) {
        last_main_imu_check = millis();
        last_udp_check = millis();
      }

      if (extended_imu_found && !first_read_ext) {
        last_extend_imu_check = millis();
      }
      
      if (myIMU.dataAvailable()) {
        last_main_imu_check = millis();
        first_read = true;
        payload.id = main_id;
        payload.x = map(myIMU.getQuatI());
        payload.y = map(myIMU.getQuatJ());
        payload.z = map(myIMU.getQuatK());
        payload.w = map(myIMU.getQuatReal());

        payloadext.id = main_id;
        payloadext.x = map(myIMU.getQuatI());
        payloadext.y = map(myIMU.getQuatJ());
        payloadext.z = map(myIMU.getQuatK());
        payloadext.w = map(myIMU.getQuatReal());

        ping.accuracy = myIMU.getQuatAccuracy();

        sendUDP(extended_imu_found);
      }

      if (extended_imu_found && myIMU2.dataAvailable()) {
        last_extend_imu_check = millis();
        first_read_ext = true;
        payloadext.id_ext = extended_id;
        payloadext.x_ext = map(myIMU2.getQuatI());
        payloadext.y_ext = map(myIMU2.getQuatJ());
        payloadext.z_ext = map(myIMU2.getQuatK());
        payloadext.w_ext = map(myIMU2.getQuatReal());

        ping.accuracy_ext = myIMU2.getQuatAccuracy();
      }

      if ((serverPort != 0) && (millis() - last_ping >= 1000)) {
        last_ping = millis();
        ping.id = main_id;
        ping.id_ext = extended_id;
        ping.batt = battery_voltage();
        ping.mode = imu_mode;
        ping.mode_ext = imu_mode_ext;
        ping.wifi_power = wifi_power;
        ping.wifi_sleep = wifi_sleep;
        udp.beginPacket(udpAddress,serverPort);
        udp.write((uint8_t*)&ping, sizeof(ping));
        udp.endPacket();
        DEBUG_PRINT.println(ping.batt);
      }

      if (millis() - last_main_imu_check >= 1000) {
        ESP.deepSleep(1000);
      }

      if (extended_imu_found && (millis() - last_extend_imu_check >= 1000)) {
        ESP.deepSleep(1000);
      }

      if (streaming_udp) {
        if (millis() - last_udp_check >= 1000) {
          ESP.deepSleep(1000);
        }
      }
                  
      blink_led(5000);
    }
    
    else {
      if (millis() - last_broadcast >= 1000) {
        last_broadcast = millis();
        Audp.broadcastTo((uint8_t*)&pingbroad, sizeof(pingbroad), broadPort);
        DEBUG_PRINT.println("Pinged");
      } 
      blink_led(2000);
    }
  }
  else {
    blink_led(1000);
  }
  if (millis() - recv_watchdog >= 5000) {
    udpAddress = IPAddress(0, 0, 0, 0);
    serverPort = 0;
    driverPort = 0;
    streaming_udp = false;
    imu_start = false;
  }
}

void connectToWiFi(const char * ssid, const char * pwd){
  DEBUG_PRINT.println("Connecting to WiFi network: " + String(ssid));
  WiFi.disconnect(true);
  WiFi.onEvent(WiFiEvent);
  WiFi.begin(ssid, pwd);
  esp_wifi_set_max_tx_power(wifi_power);
  WiFi.setSleep(wifi_sleep);
  DEBUG_PRINT.println("Waiting for WIFI connection...");
}

void WiFiEvent(WiFiEvent_t event){
    switch(event) {
      case SYSTEM_EVENT_STA_GOT_IP: 
          DEBUG_PRINT.print("WiFi connected! IP address: ");
          DEBUG_PRINT.println(WiFi.localIP());  
          udp.begin(WiFi.localIP(),broadPort);
          last_broadcast = millis();
          last_ping = millis();
          last_main_imu_check = millis();
          last_extend_imu_check = millis();
          last_udp_check = millis();
          recv_watchdog = millis();
          connected = true;
          break;
      case SYSTEM_EVENT_STA_DISCONNECTED:
          DEBUG_PRINT.println("WiFi lost connection");
          connected = false;
          udpAddress = IPAddress(0, 0, 0, 0);
          serverPort = 0;
          driverPort = 0;
          streaming_udp = false;
          imu_start = false;
          WiFi.reconnect();
          break;
      default: break;
    }
}

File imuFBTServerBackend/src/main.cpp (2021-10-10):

#include <globals.h>
#include <serverudp.h>
#include <driverudp.h>
#include <driverstruct.h>

using namespace vr;
using namespace Eigen;

#define TARGET_RESOLUTION_MS 1
#define TARGET_INTERVAL_MS 5


Quaternionf imu_lfoot(1, 0, 0, 0);
Quaternionf imu_rfoot(1, 0, 0, 0);
Quaternionf imu_lshin(1, 0, 0, 0);
Quaternionf imu_rshin(1, 0, 0, 0);
Quaternionf imu_lthigh(1, 0, 0, 0);
Quaternionf imu_rthigh(1, 0, 0, 0);
Quaternionf imu_waist(1, 0, 0, 0);
Quaternionf imu_chest(1, 0, 0, 0);
Quaternionf imu_lshoulder(1, 0, 0, 0);
Quaternionf imu_rshoulder(1, 0, 0, 0);
Quaternionf imu_lupperarm(1, 0, 0, 0);
Quaternionf imu_rupperarm(1, 0, 0, 0);

bool lfoot_available = false;
bool rfoot_available = false;
bool lshin_available = false;
bool rshin_available = false;
bool lthigh_available = false;
bool rthigh_available = false;
bool waist_available = false;
bool chest_available = false;
bool lshoulder_available = false;
bool rshoulder_available = false;
bool lupperarm_available = false;
bool rupperarm_available = false;
bool hmd_available = false;

bool init_recv = false;
bool feet_en = false;
bool shin_en = false;
bool thigh_en = false;
bool waist_en = false;
bool chest_en = false;
bool shoulder_en = false;
bool upperarm_en = false;

bool override_feet = false;

BodyKinematics* bk = new BodyKinematics();
Matrix3f mat_hmd = Matrix3f::Identity(3, 3);
Vector3f p_hmd(0, 0, 0);

bool stream_viewer_data = false;


std::chrono::high_resolution_clock::time_point t_hmd_end = std::chrono::high_resolution_clock::now();
std::chrono::high_resolution_clock::time_point t_hmd_last = std::chrono::high_resolution_clock::now();
std::chrono::high_resolution_clock::time_point t_viewer_last = std::chrono::high_resolution_clock::now();
double hmd_elapsed_time_ms;


IVRSystem* sys;

TIMECAPS tc;
UINT wTimerRes;
MMRESULT mmresult;
MMRESULT timer_id;

serverudp* udpS = new serverudp();
driverudp* udpD = new driverudp();

bool loop = false;

DriverPayload driverpayload;

void sendPayload(int i, bool viewer=false) {

	driverpayload.header = (uint8_t)'I';
	driverpayload.footer = (uint8_t)'i';

	driverpayload.hmd_available = hmd_available;

	switch (i) {

	case LFOOT:
		driverpayload.id = LFOOT;

		if (!override_feet) {
			driverpayload.available = lfoot_available;
			driverpayload.Px = bk->P_lfoot.x();
			driverpayload.Py = bk->P_lfoot.y();
			driverpayload.Pz = bk->P_lfoot.z();
			driverpayload.Qx = map(bk->Q_lfoot.x());
			driverpayload.Qy = map(bk->Q_lfoot.y());
			driverpayload.Qz = map(bk->Q_lfoot.z());
			driverpayload.Qw = map(bk->Q_lfoot.w());
		}
		else {
			driverpayload.available = lshin_available;
			driverpayload.Px = bk->P_lshin.x();
			driverpayload.Py = bk->P_lshin.y();
			driverpayload.Pz = bk->P_lshin.z();
			driverpayload.Qx = map(bk->Q_lshin.x());
			driverpayload.Qy = map(bk->Q_lshin.y());
			driverpayload.Qz = map(bk->Q_lshin.z());
			driverpayload.Qw = map(bk->Q_lshin.w());
		}
		
		
		switch (viewer) {
		case true:
			udpS->send((char*)&driverpayload, sizeof(driverpayload));
			break;
		case false:
			if (feet_en) {
				udpD->send((char*)&driverpayload, sizeof(driverpayload));
			}
			break;
		}
		break;

	case RFOOT:
		driverpayload.id = RFOOT;

		if (!override_feet) {
			driverpayload.available = rfoot_available;
			driverpayload.Px = bk->P_rfoot.x();
			driverpayload.Py = bk->P_rfoot.y();
			driverpayload.Pz = bk->P_rfoot.z();
			driverpayload.Qx = map(bk->Q_rfoot.x());
			driverpayload.Qy = map(bk->Q_rfoot.y());
			driverpayload.Qz = map(bk->Q_rfoot.z());
			driverpayload.Qw = map(bk->Q_rfoot.w());
		}
		else {
			driverpayload.available = rshin_available;
			driverpayload.Px = bk->P_rshin.x();
			driverpayload.Py = bk->P_rshin.y();
			driverpayload.Pz = bk->P_rshin.z();
			driverpayload.Qx = map(bk->Q_rshin.x());
			driverpayload.Qy = map(bk->Q_rshin.y());
			driverpayload.Qz = map(bk->Q_rshin.z());
			driverpayload.Qw = map(bk->Q_rshin.w());
		}
		
		
		switch (viewer) {
		case true:
			udpS->send((char*)&driverpayload, sizeof(driverpayload));
			break;
		case false:
			if (feet_en) {
				udpD->send((char*)&driverpayload, sizeof(driverpayload));
			}
			break;
		}
		break;

	case LSHIN:
		driverpayload.id = LSHIN;
		driverpayload.available = lshin_available;
		driverpayload.Px = bk->P_lshin.x();
		driverpayload.Py = bk->P_lshin.y();
		driverpayload.Pz = bk->P_lshin.z();
		driverpayload.Qx = map(bk->Q_lshin.x());
		driverpayload.Qy = map(bk->Q_lshin.y());
		driverpayload.Qz = map(bk->Q_lshin.z());
		driverpayload.Qw = map(bk->Q_lshin.w());
		
		switch (viewer) {
		case true:
			udpS->send((char*)&driverpayload, sizeof(driverpayload));
			break;
		case false:
			if (shin_en) {
				udpD->send((char*)&driverpayload, sizeof(driverpayload));
			}
			break;
		}
		break;

	case RSHIN:
		driverpayload.id = RSHIN;
		driverpayload.available = rshin_available;
		driverpayload.Px = bk->P_rshin.x();
		driverpayload.Py = bk->P_rshin.y();
		driverpayload.Pz = bk->P_rshin.z();
		driverpayload.Qx = map(bk->Q_rshin.x());
		driverpayload.Qy = map(bk->Q_rshin.y());
		driverpayload.Qz = map(bk->Q_rshin.z());
		driverpayload.Qw = map(bk->Q_rshin.w());
		
		switch (viewer) {
		case true:
			udpS->send((char*)&driverpayload, sizeof(driverpayload));
			break;
		case false:
			if (shin_en) {
				udpD->send((char*)&driverpayload, sizeof(driverpayload));
			}
			break;
		}
		break;

	case LTHIGH:
		driverpayload.id = LTHIGH;
		driverpayload.available = lthigh_available;
		driverpayload.Px = bk->P_lthigh.x();
		driverpayload.Py = bk->P_lthigh.y();
		driverpayload.Pz = bk->P_lthigh.z();
		driverpayload.Qx = map(bk->Q_lthigh.x());
		driverpayload.Qy = map(bk->Q_lthigh.y());
		driverpayload.Qz = map(bk->Q_lthigh.z());
		driverpayload.Qw = map(bk->Q_lthigh.w());
		
		switch (viewer) {
		case true:
			udpS->send((char*)&driverpayload, sizeof(driverpayload));
			break;
		case false:
			if (thigh_en) {
				udpD->send((char*)&driverpayload, sizeof(driverpayload));
			}
			break;
		}
		break;

	case RTHIGH:
		driverpayload.id = RTHIGH;
		driverpayload.available = rthigh_available;
		driverpayload.Px = bk->P_rthigh.x();
		driverpayload.Py = bk->P_rthigh.y();
		driverpayload.Pz = bk->P_rthigh.z();
		driverpayload.Qx = map(bk->Q_rthigh.x());
		driverpayload.Qy = map(bk->Q_rthigh.y());
		driverpayload.Qz = map(bk->Q_rthigh.z());
		driverpayload.Qw = map(bk->Q_rthigh.w());
		
		switch (viewer) {
		case true:
			udpS->send((char*)&driverpayload, sizeof(driverpayload));
			break;
		case false:
			if (thigh_en) {
				udpD->send((char*)&driverpayload, sizeof(driverpayload));
			}
			break;
		}
		break;
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

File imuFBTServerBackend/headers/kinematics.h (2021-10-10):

#pragma once

#include <Eigen/Dense>
#include <math.h>

#define PI 3.14159265359

using namespace Eigen;

class BodyKinematics {

public:

	EIGEN_MAKE_ALIGNED_OPERATOR_NEW

	BodyKinematics()
	{
		Q_lfoot = Quaternionf(1, 0, 0, 0);
		Q_rfoot = Quaternionf(1, 0, 0, 0);
		Q_lshin = Quaternionf(1, 0, 0, 0);
		Q_rshin = Quaternionf(1, 0, 0, 0);
		Q_lthigh = Quaternionf(1, 0, 0, 0);
		Q_rthigh = Quaternionf(1, 0, 0, 0);
		Q_waist = Quaternionf(1, 0, 0, 0);
		Q_chest = Quaternionf(1, 0, 0, 0);
		Q_lshoulder = Quaternionf(1, 0, 0, 0);
		Q_rshoulder = Quaternionf(1, 0, 0, 0);
		Q_lupperarm = Quaternionf(1, 0, 0, 0);
		Q_rupperarm = Quaternionf(1, 0, 0, 0);

		P_lfoot = Vector3f(0, 0, 0);
		P_rfoot = Vector3f(0, 0, 0);
		P_lshin = Vector3f(0, 0, 0);
		P_rshin = Vector3f(0, 0, 0);
		P_lthigh = Vector3f(0, 0, 0);
		P_rthigh = Vector3f(0, 0, 0);
		P_waist = Vector3f(0, 0, 0);
		P_chest = Vector3f(0, 0, 0);
		P_lshoulder = Vector3f(0, 0, 0);
		P_rshoulder = Vector3f(0, 0, 0);
		P_lupperarm = Vector3f(0, 0, 0);
		P_rupperarm = Vector3f(0, 0, 0);

		T_driver = Quaternionf(1, 0, 0, 0);

		T_lfoot = Quaternionf(1, 0, 0, 0);
		T_rfoot = Quaternionf(1, 0, 0, 0);
		T_lshin = Quaternionf(1, 0, 0, 0);
		T_rshin = Quaternionf(1, 0, 0, 0);
		T_lthigh = Quaternionf(1, 0, 0, 0);
		T_rthigh = Quaternionf(1, 0, 0, 0);
		T_waist = Quaternionf(1, 0, 0, 0);
		T_chest = Quaternionf(1, 0, 0, 0);
		T_lshoulder = Quaternionf(1, 0, 0, 0);
		T_rshoulder = Quaternionf(1, 0, 0, 0);
		T_lupperarm = Quaternionf(1, 0, 0, 0);
		T_rupperarm = Quaternionf(1, 0, 0, 0);

		offset_level_lfoot = Quaternionf(1, 0, 0, 0);
		offset_level_rfoot = Quaternionf(1, 0, 0, 0);
		offset_level_lshin = Quaternionf(1, 0, 0, 0);
		offset_level_rshin = Quaternionf(1, 0, 0, 0);
		offset_level_lthigh = Quaternionf(1, 0, 0, 0);
		offset_level_rthigh = Quaternionf(1, 0, 0, 0);
		offset_level_waist = Quaternionf(1, 0, 0, 0);
		offset_level_chest = Quaternionf(1, 0, 0, 0);
		offset_level_lshoulder = Quaternionf(1, 0, 0, 0);
		offset_level_rshoulder = Quaternionf(1, 0, 0, 0);
		offset_level_lupperarm = Quaternionf(1, 0, 0, 0);
		offset_level_rupperarm = Quaternionf(1, 0, 0, 0);

		offset_heading_lfoot = Quaternionf(1, 0, 0, 0);
		offset_heading_rfoot = Quaternionf(1, 0, 0, 0);
		offset_heading_lshin = Quaternionf(1, 0, 0, 0);
		offset_heading_rshin = Quaternionf(1, 0, 0, 0);
		offset_heading_lthigh = Quaternionf(1, 0, 0, 0);
		offset_heading_rthigh = Quaternionf(1, 0, 0, 0);
		offset_heading_waist = Quaternionf(1, 0, 0, 0);
		offset_heading_chest = Quaternionf(1, 0, 0, 0);
		offset_heading_lshoulder = Quaternionf(1, 0, 0, 0);
		offset_heading_rshoulder = Quaternionf(1, 0, 0, 0);
		offset_heading_lupperarm = Quaternionf(1, 0, 0, 0);
		offset_heading_rupperarm = Quaternionf(1, 0, 0, 0);

		shin = 0.5;
		thigh = 0.4;
		lback = 0.25;
		uback = 0.35;
		head = 0.2;
		shoulder = 0.1;
		hip_width = 0.3;
		shoulder_width = 0.3;
		foot_sensor = 0.05;
		shin_sensor = 0.2;
		thigh_sensor = 0.2;
		waist_sensor = 0.2;
		chest_sensor = 0.2;
		shoulder_sensor = 0.1;
		upperarm_sensor = 0.15;
		floor_offset = 0.0;

		lfoot_sensor_offset = Vector2f(0, 0);
		rfoot_sensor_offset = Vector2f(0, 0);
		lshin_sensor_offset = Vector2f(0, 0);
		rshin_sensor_offset = Vector2f(0, 0);
		lthigh_sensor_offset = Vector2f(0, 0);
		rthigh_sensor_offset = Vector2f(0, 0);
		waist_sensor_offset = Vector2f(0, 0);
		chest_sensor_offset = Vector2f(0, 0);
		lshoulder_sensor_offset = Vector2f(0, 0);
		rshoulder_sensor_offset = Vector2f(0, 0);
		lupperarm_sensor_offset = Vector2f(0, 0);
		rupperarm_sensor_offset = Vector2f(0, 0);
		head_sensor_offset = Vector2f(0, 0);
	}

	// Euler XYZ to quaternion
	Quaternionf euXYZ_to_quat(float x, float y, float z) {
		AngleAxisf X(x, Eigen::Vector3f::UnitX());
		AngleAxisf Y(y, Eigen::Vector3f::UnitY());
		AngleAxisf Z(z, Eigen::Vector3f::UnitZ());

		Quaternionf q = X * Y * Z;
		return q;
	}

	// Euler YXZ to quaternion
	Quaternionf euYXZ_to_quat(float y, float x, float z) {
		AngleAxisf X(x, Eigen::Vector3f::UnitX());
		AngleAxisf Y(y, Eigen::Vector3f::UnitY());
		AngleAxisf Z(z, Eigen::Vector3f::UnitZ());

		Quaternionf q = Y * X * Z;
		return q;
	}

	//Set positional parameters when in T-pose (body segment length and sensor position)
	void setParam(float shin, float thigh, float lback, float uback, float head, float shoulder, float hip_width, float shoulder_width, float foot_sensor, float shin_sensor, float thigh_sensor, float waist_sensor, float chest_sensor, float shoulder_sensor, float upperarm_sensor, float floor_offset) {
		this->shin = shin;						// knee to foot segment length
		this->thigh = thigh;					// knee to hip segment length
		this->lback = lback;					// hip to mid back segment length
		this->uback = uback;					// mid back to neck segment length
		this->head = head;						// neck to headset segment length
		this->shoulder = shoulder;				// neck to sholder segment length
		this->hip_width = hip_width;			// hip horizontal width
		this->shoulder_width = shoulder_width;	// shoulder horizontal width
		this->foot_sensor = foot_sensor;		// ankle joint to foot sensor position
		this->shin_sensor = shin_sensor;		// knee joint to shin sensor position
		this->thigh_sensor = thigh_sensor;		// hip joint to thigh sensor position
		this->waist_sensor = waist_sensor;		// hip joint to waist sensor position
		this->chest_sensor = chest_sensor;		// mid back joint to chest sensor position
		this->shoulder_sensor = shoulder_sensor;// body centre line to shoulder sensor position
		this->upperarm_sensor = upperarm_sensor;// shoulder joint to upper arm sensor position
		this->floor_offset = floor_offset;		// tracker min Y value
	}

	//Set sensor offset position when in T-pose
	void setSensorOffset(const Vector2f& lfoot, const Vector2f& rfoot, const Vector2f& lshin, const Vector2f& rshin, const Vector2f& lthigh, const Vector2f& rthigh, const Vector2f& waist, const Vector2f& chest, const Vector2f& lshoulder, const Vector2f& rshoulder, const Vector2f& lupperarm, const Vector2f& rupperarm, const Vector2f& head) {
		lfoot_sensor_offset = lfoot;
		rfoot_sensor_offset = rfoot;
		lshin_sensor_offset = lshin;
		rshin_sensor_offset = rshin;
		lthigh_sensor_offset = lthigh;
		rthigh_sensor_offset = rthigh;
		waist_sensor_offset = waist;
		chest_sensor_offset = chest;
		lshoulder_sensor_offset = lshoulder;
		rshoulder_sensor_offset = rshoulder;
		lupperarm_sensor_offset = lupperarm;
		rupperarm_sensor_offset = rupperarm;
		head_sensor_offset = head;
	}

	// Transform from IMU frame to driver frame (X right, Y up, Z back)
	void setDriverTransform(const Quaternionf& T_driver) {
		this->T_driver = T_driver;
	}
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

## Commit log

2021-06-14 Update files and folders
    [frame.obj]
2021-06-28 Update to v0.2
    1. Added chest sensor support
    2. Added Calibration button on desktop app for sensor realignment/calibration
    3. Added WiFi configuration via desktop app
    [LiPo-803040.SLDPRT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]
2021-07-10 Added Battery % in desktop app
    1. Added Battery % in desktop app.
    2. Removed unnecessary controller components.
2021-07-15 Separate forward kinematics thread from RunFrame()
    1. Separate forward kinematics thread from RunFrame()
    2. Remove tracker calibration with SteamVR view reset
2021-07-15 BOM list
    [BOM for 1 tracker.xlsx]
2021-08-05 Update hardware example
    [BOM for 1 tracker extension.xlsx, BOM for 1 tracker.xlsx, GY-BNO08X.SLDPRT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]
2021-08-05 Added feet tracking, shoulder tracking and elbow tracking
    1. Added feet tracking, shoulder tracking and elbow tracking
    2. Fixed SteamVR stuck in UDP while loop upon exiting
    [ImuUDP.h, esp32_FBT.ino]
2021-08-10 Added option for SteamVR tracker device activation
    1. Added option for SteamVR tracker device activation
    2. Added settings to set tracker floor level offset
2021-08-29 Added improvement features
    1. Added option to enable/disable ESP32 WiFi power saving mode
    2. Added total height indicator in desktop app
    3. Increased timeout interval
    4. Auto restart ESP32 when error happens (UDP error, sensor error)
    [esp32_FBT.ino, main.py]
2021-09-02 Minor improvement for auto reset check
    [esp32_FBT.ino]
2021-09-23 v0.7 update
    1. Added option to manually connect tracker in desktop app
    2. Added option to set and display tracker IMU reporting mode in desktop app
    3. Added option to set and display tracker WiFi TX power in desktop app
    4. Added option to set and display tracker WiFi power saving mode in desktop app
    5. Added option to measure VR headset height in desktop app
    6. Show SteamVR status in desktop app
2021-10-10 0.7.1
    1. Moved kinematics and IMU data receiving process to desktop app backend
    2. Minor desktop app restructuring
    3. Added IMU accuracy tab in desktop app
    4. Added tracker output data tab in desktop app
